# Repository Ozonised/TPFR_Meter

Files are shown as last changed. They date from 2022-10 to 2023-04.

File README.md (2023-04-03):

# TPFR_Meter
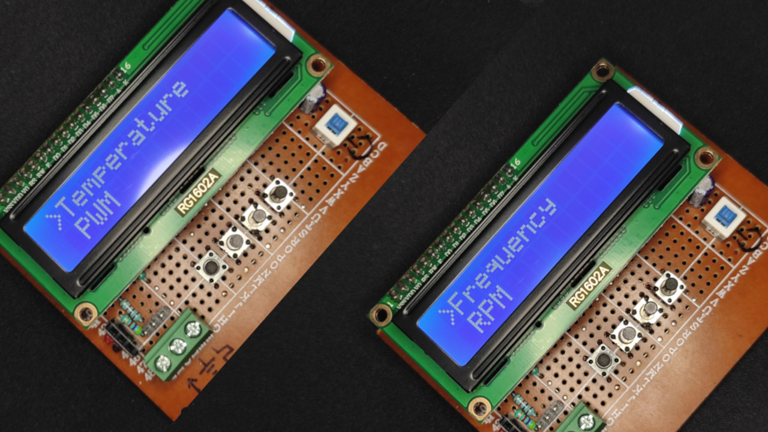
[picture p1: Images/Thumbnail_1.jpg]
TPFR_Meter


This is an ATmega328p based Temperature, PWM generator, Frequency counter and RPM meter. 
# BACK STORY
Often when creating circuits involving MOSFETs or motor drivers, I happen to find a need for a temperature sensor to measure the temperatures of my MOSFETs, a PWM generator to control the speed of motors or to test servos. Not only did have a need for a PWM generator but also a frequency counter when tinkering around with ne555 cicuits based oscillator circuits. Designing separate circuits to fullfill each of my needs would prove to time consuming, expensive and would require additional space to store all the devices. Thus, the idea of creating all purpose meter to measure temperature, generate PWM signals, measure Frequency and RPM struck me which resulted in me creating this multi purpose meter called the TPFR meter. 

# What does TPFR mean?
Well TPFR stands for Temperature(T), PWM(P), Frequency(F) and RPM(R) which is representative of the functionality of this meter.

# FEATURES: 
## 1. TEMPERATURE
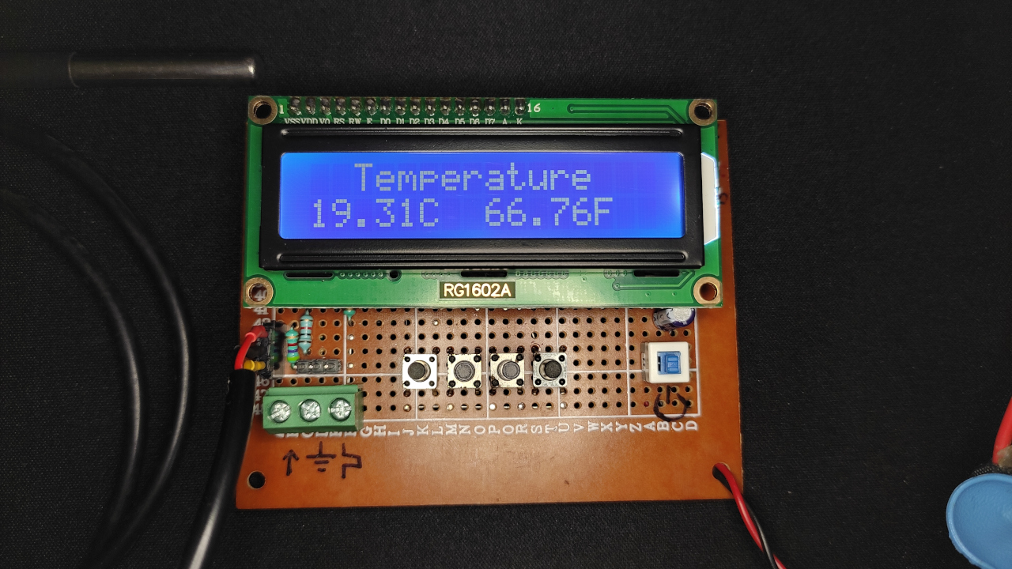
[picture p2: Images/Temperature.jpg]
TEMPERATURE


The temperature measurement is done with the help of a ds18b20 waterproof temperature sensor with a max measurable temperature of 125 degree celsius and a minimum of -55 degree celsius.

## 2. PWM
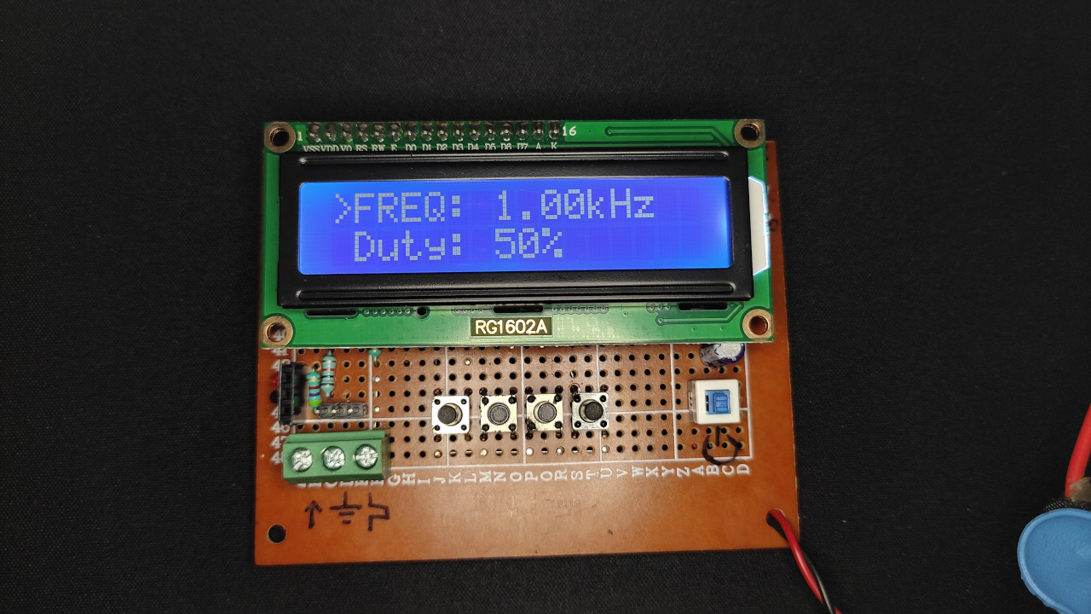
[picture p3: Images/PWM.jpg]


The PWM signals are generated using the timer1 of the 328p with a frequency range of 31Hz - 100KHz and a variable duty cycle from 0 - 100%.
The frequency range is subdivied into 4 ranges:

| Range | Frequency Range |
| :---: | :---: |
| 1 | 31Hz - 1KHz |
| 2 | 1KHz - 10KHz |
| 3 | 10KHz - 40KHz |
| 4 | 40KHz - 100KHz |

## 3. FREQUENCY COUNTER
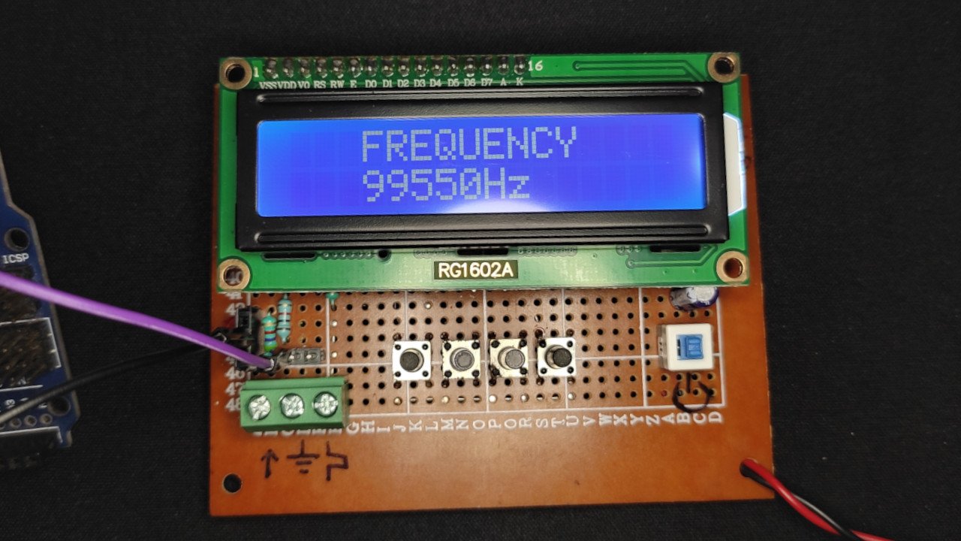
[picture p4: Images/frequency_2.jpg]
FREQUENCY_COUNTER


The frequency counter mode as the name implies measures the frequency of the input signal with an accuracy of 99.8%. The error% is usually around 0.02% - 0.01%. The maximum error% that I recorded was 0.2%. I do not know the maximum measurable frequency since my test setup could only reach a maximum frequency of 100Khz.

## 4. RPM
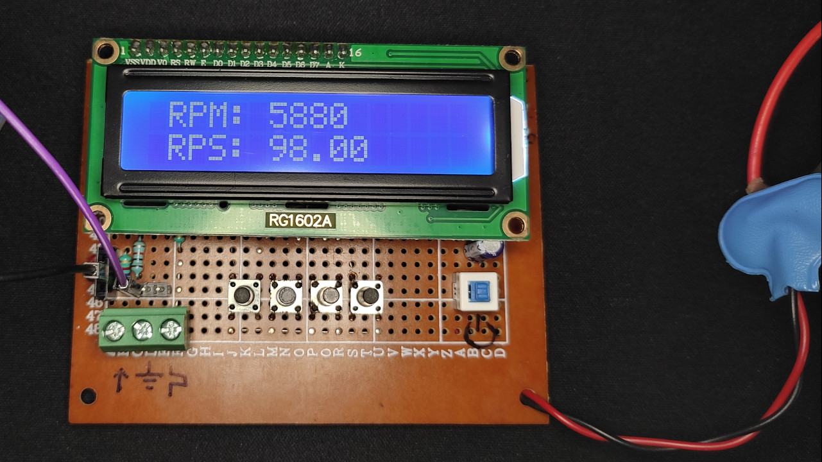
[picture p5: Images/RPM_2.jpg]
RPM


This mode uses the timer1's input capture register to measure the period of the input signal and then computes the revolution per minute(RPM) and the revolution per second(RPS). The maximum measurable RPM is in the vicinity of 100,000 RPM(approx). Unfortunately, I do not have the equipment to measure the actual maximum RPM.

 ### Measuring RPM:
 1. To measure the RPM, an [IR proximity sensor](https://hackster.imgix.net/uploads/attachments/471152/obstacle-avoidance-tracking-infrared-sensor-module_S9CxCA7UqZ.jpg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) is used.
 2. The RPM of the object to measured, a wheel in my case, is covered by a black tape with a white spot on it. The white spot is needed to reflect the IR light which in turn triggers the output of the IR sensor.
 
 ### Note: 
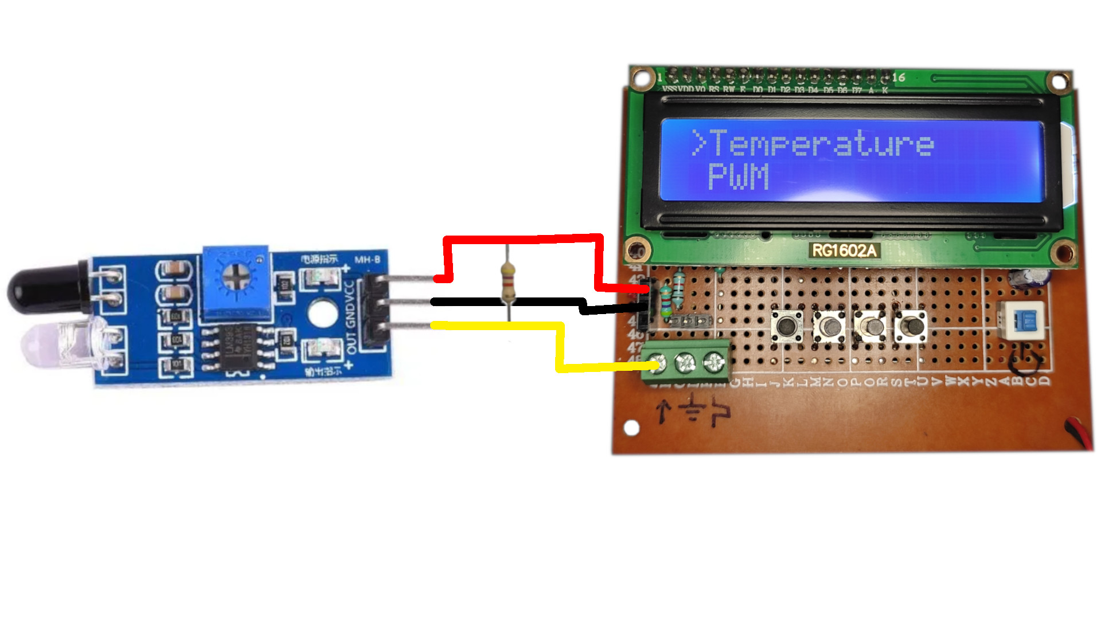
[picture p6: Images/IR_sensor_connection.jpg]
connection of IR sensor
 The output of the IR sensor must be pulled up to VCC using a pull up resistor of 4.7K or so. This is because the IR sensor has an open collector output ,i.e, the output can only be pulled LOW so a pull up resistor is needed to avoid a floating pin. Refer to the connection diagram below: 
 
# ELECTRICAL CHARACTERISTICS:
 | Pin | Voltage |
 | :---: | :---: |
 | Input | 7.5V - 12V |
 | PWM | 5V |
 | Frequency Counter | 5V |
 | dsb18b20 data pin | 5V |

# USER INTERFACE: 
To use the this device, we must be aware of the hardware as well as the software interface and that is what we will be covering in this section starting with the pinout.

## PINOUT:
 Seeing all those switches and connector might seem intimidating at first but don't you worry as that is what I will breaking down in this section.
 
 pinout
 
 Each connector and switch in the picture has been designated with a number to aid with it's identification in the table below:
 
 | Pin No | Function |
 | :----: | :------: |
 | 1 | 5V |
 | 2 | GND |
 | 3 | dsb18b20 data pin |
 | 4 | Frequency counter |
 | 5 | GND |
 | 6 | PWM |
 | 7 | BACK |
 | 8 | UP / Increament |
 | 9 | DOWN / Decreament |
 | 10 | ENTER / SELECT |
 | 11 | Power switch |
 
 ## HOW TO USE:
- Connect a 9v battery and press the power button. 
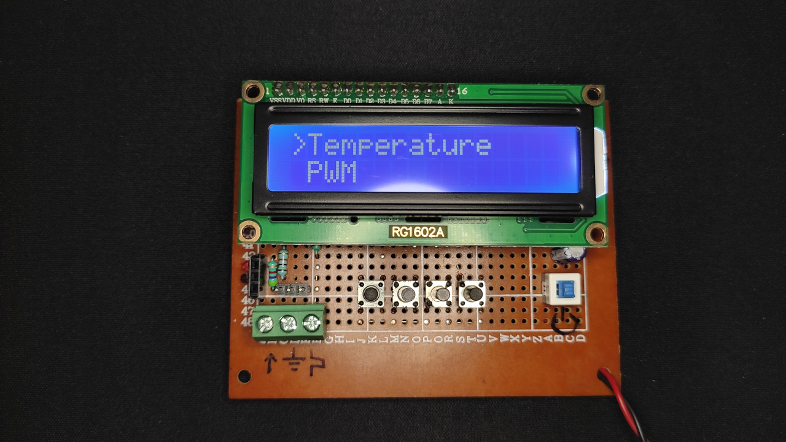
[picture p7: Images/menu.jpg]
menupage
- On startup you will be greated with the homescreen/menupage.  
- The cursor on the right points to the current selected the option. 
- Use the ```UP``` and ```DOWN``` buttons to navigate through the menu.
- Press the ```ENTER``` button to enter the menu or option.
- Press the ```BACK``` button to exit from the current option.

That's the basic on how to use the meter. However taking a look at an example will provide a broader picture.
Let's take the example of the PWM mode:
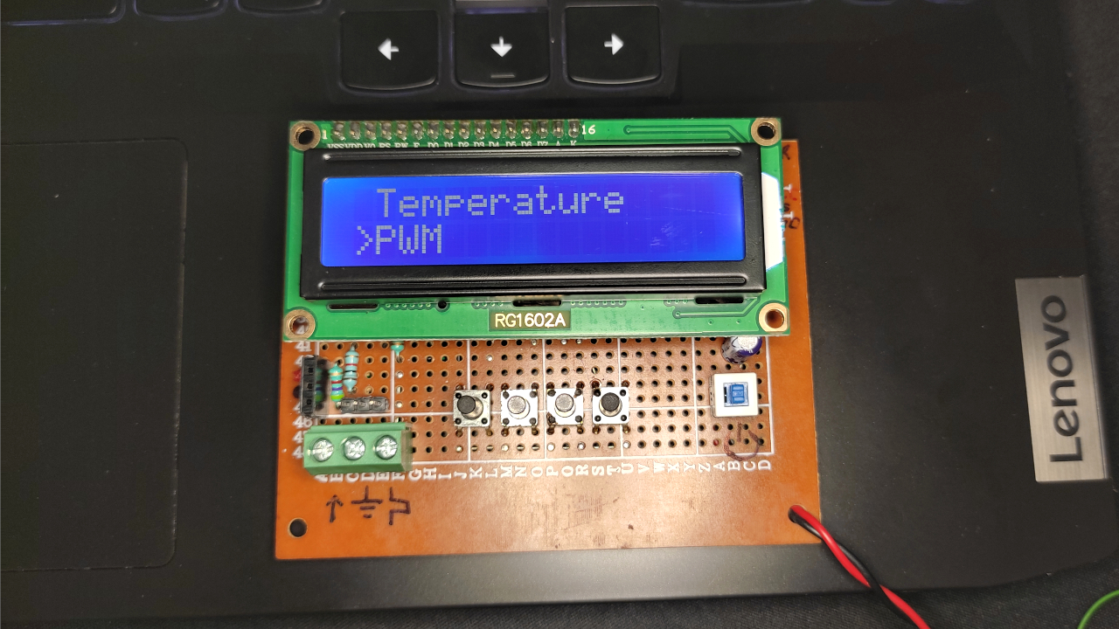
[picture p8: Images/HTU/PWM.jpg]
- Press the ```DOWN``` switch to point the arrow at the ```PWM``` mode. 
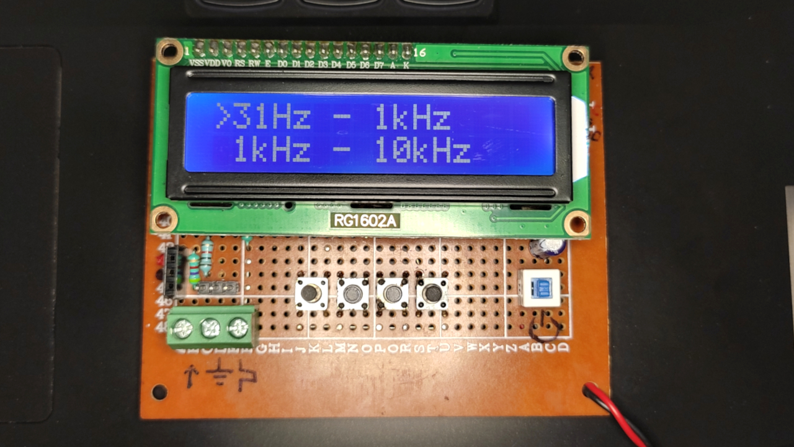
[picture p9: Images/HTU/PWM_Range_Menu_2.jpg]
PWM_Range
- Press ```ENTER``` to enter PWM mode. 
- Now, you will be greeted with the PWM frequency range menu. The PWM frequency range is subdivied into 4 ranges:

   | Range | Frequency Range |
   | :---: | :---: |
   | 1 | 31Hz - 1KHz |
   | 2 | 1KHz - 10KHz |
   | 3 | 10KHz - 40KHz |
   | 4 | 40KHz - 100KHz |
   
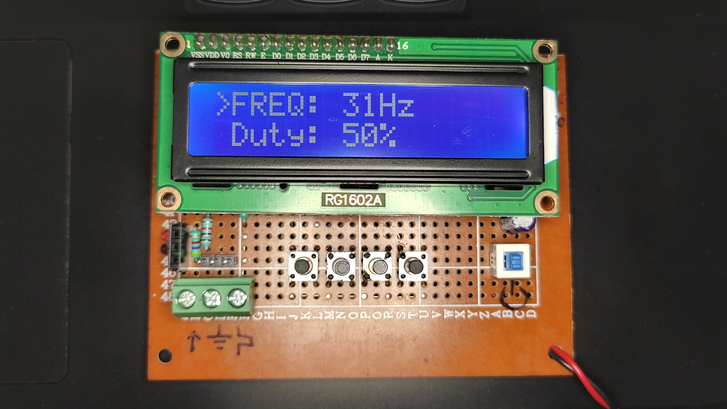
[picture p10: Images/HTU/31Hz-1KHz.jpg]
firstRange
- Let's select the first range(31HZ - 1KHz) by pressing ```ENTER```. 
- Now you will be presented with 2 options and those are frequency(```Freq:```) and  duty cycle (```Duty%:```). By default the frequency is set to the lowest value in the given range(31Hz in this case) while the duty cycle is set to to 50.
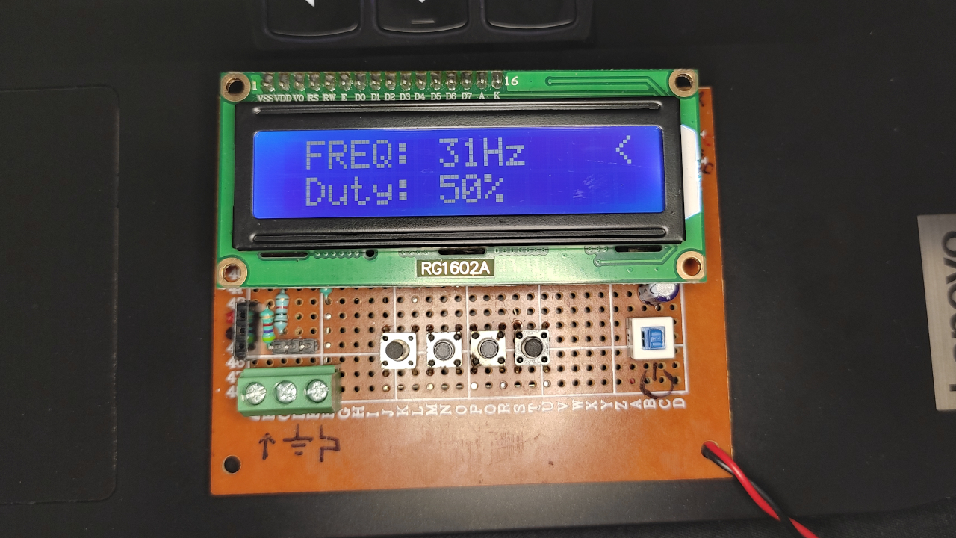
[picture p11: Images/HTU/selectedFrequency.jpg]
freq_edit
- To change the default value, the frequency value in this case, press ```ENTER```. 
- Now the cursor shifts to the right hand side, implying that you are in the value edit mode.
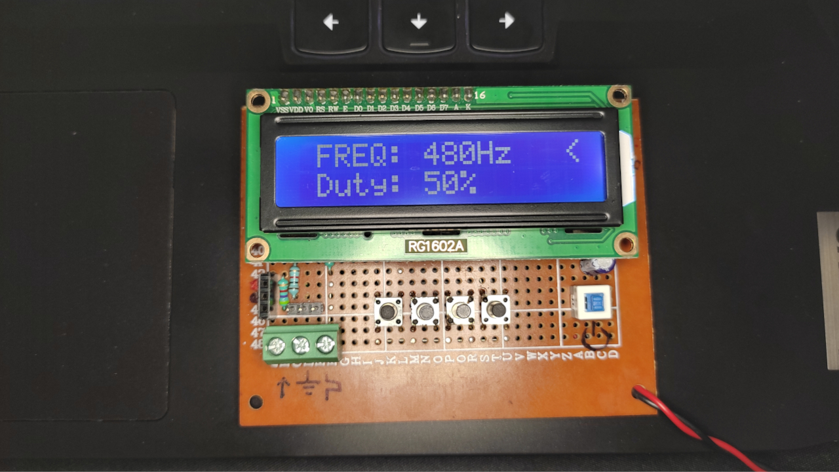
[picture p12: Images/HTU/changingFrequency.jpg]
changingFreq
- Press the ```UP``` or ```DOWN``` button to either increament or decreament the values in single steps or long press the respective button to rapidly increase or decrease the value. 
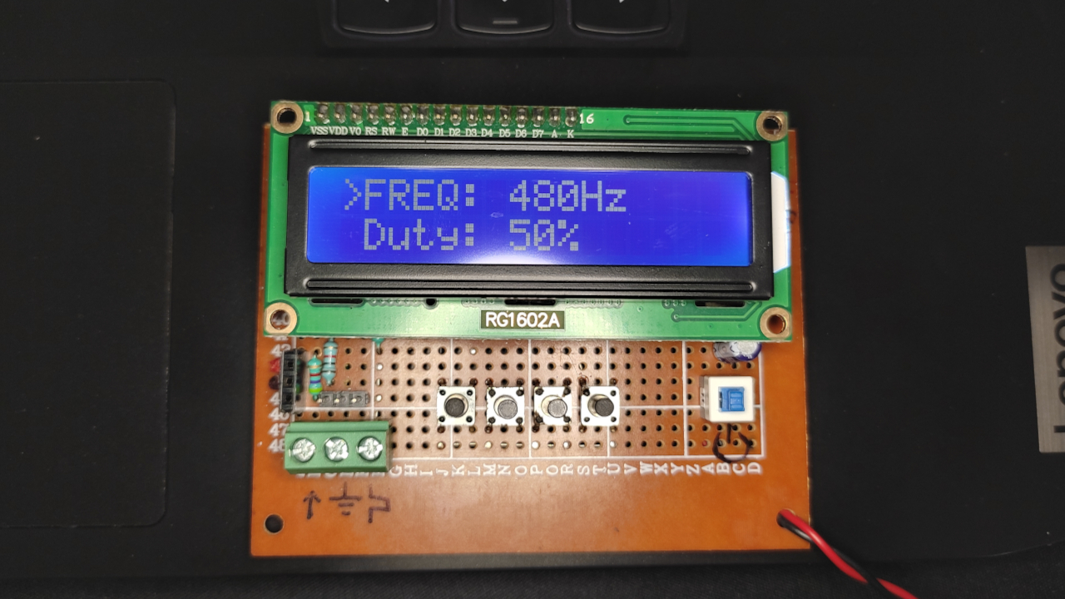
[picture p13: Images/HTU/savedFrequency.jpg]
savingFreq
- Once you have set the desired value, press ```ENTER``` to save it and the cursor moves back to the left hand side. 
- The same steps are applicable for changing the duty cycle value.
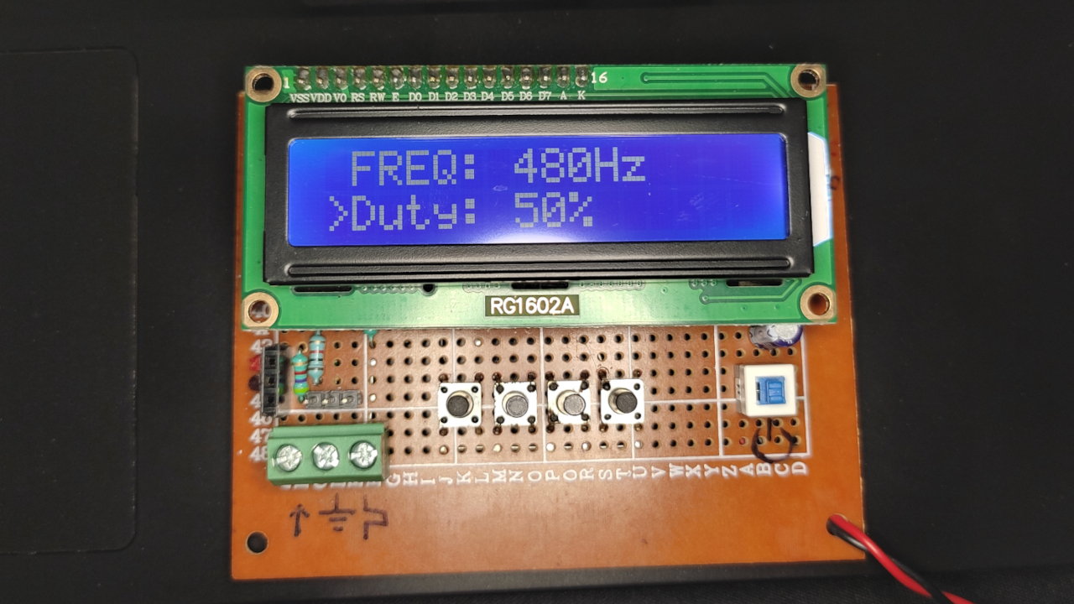
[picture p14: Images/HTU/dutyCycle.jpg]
dutyCycle
- First, press the ```DOWN``` button to select duty cycle. 
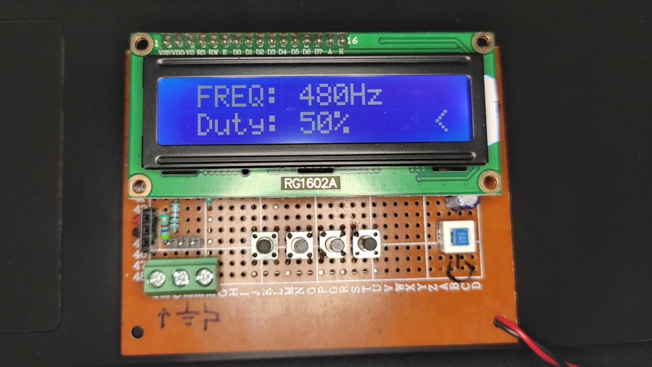
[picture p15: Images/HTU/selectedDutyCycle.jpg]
dutyCycleSelected
- Now press ```ENTER``` to select it and the cursor moves to the right hand side implying you are in the value edit mode. 
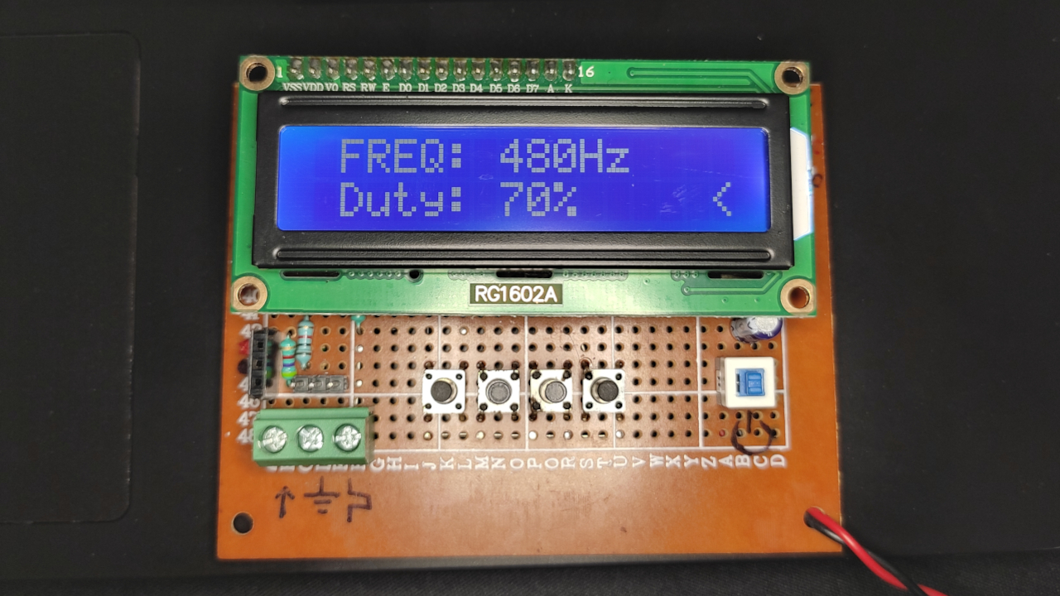
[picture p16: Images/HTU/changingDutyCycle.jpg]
changingDutyCycle
- Now change the value by either pressing the ```UP``` or ```DOWN``` button. The procedure is as the same as the one shown above for frequency. 
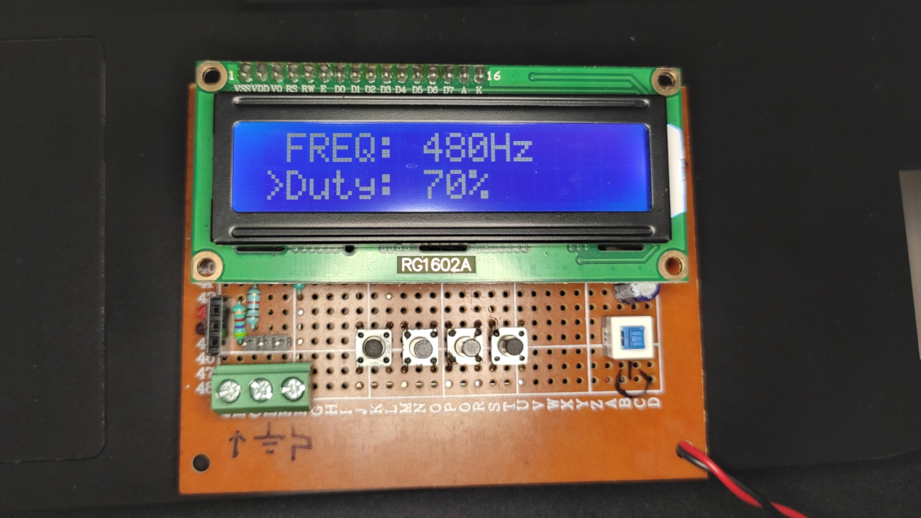
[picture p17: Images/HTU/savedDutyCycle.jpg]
savedDutyCycle
- Press ```ENTER``` to save the value. 
- To exit from the PWM menu, press the ```BACK``` button. PWM_Range
- Press ```BACK``` again to get to the homescreen. PWM

## DONE THIS IS IT! 
This is all you need to know to get started using this meter.

### Note: 
- The frequency and duty cycle change only upon pressing ```ENTER```.
- The frequency increment step is not 1Hz for every range. It changes with the frequency range. The table below shows the shows the frequecny range and it's increament/decreament step value:

| | Frequency Range | Step Value |
| :---: | :---: | :---: |
| 1 | 31Hz - 1KHz | 1Hz |
| 2 | 1KHz - 10KHz | 10Hz |
| 3 | 10KHz - 40KHz | 100Hz |
| 4 | 40KHz - 100KHz | 1000Hz |

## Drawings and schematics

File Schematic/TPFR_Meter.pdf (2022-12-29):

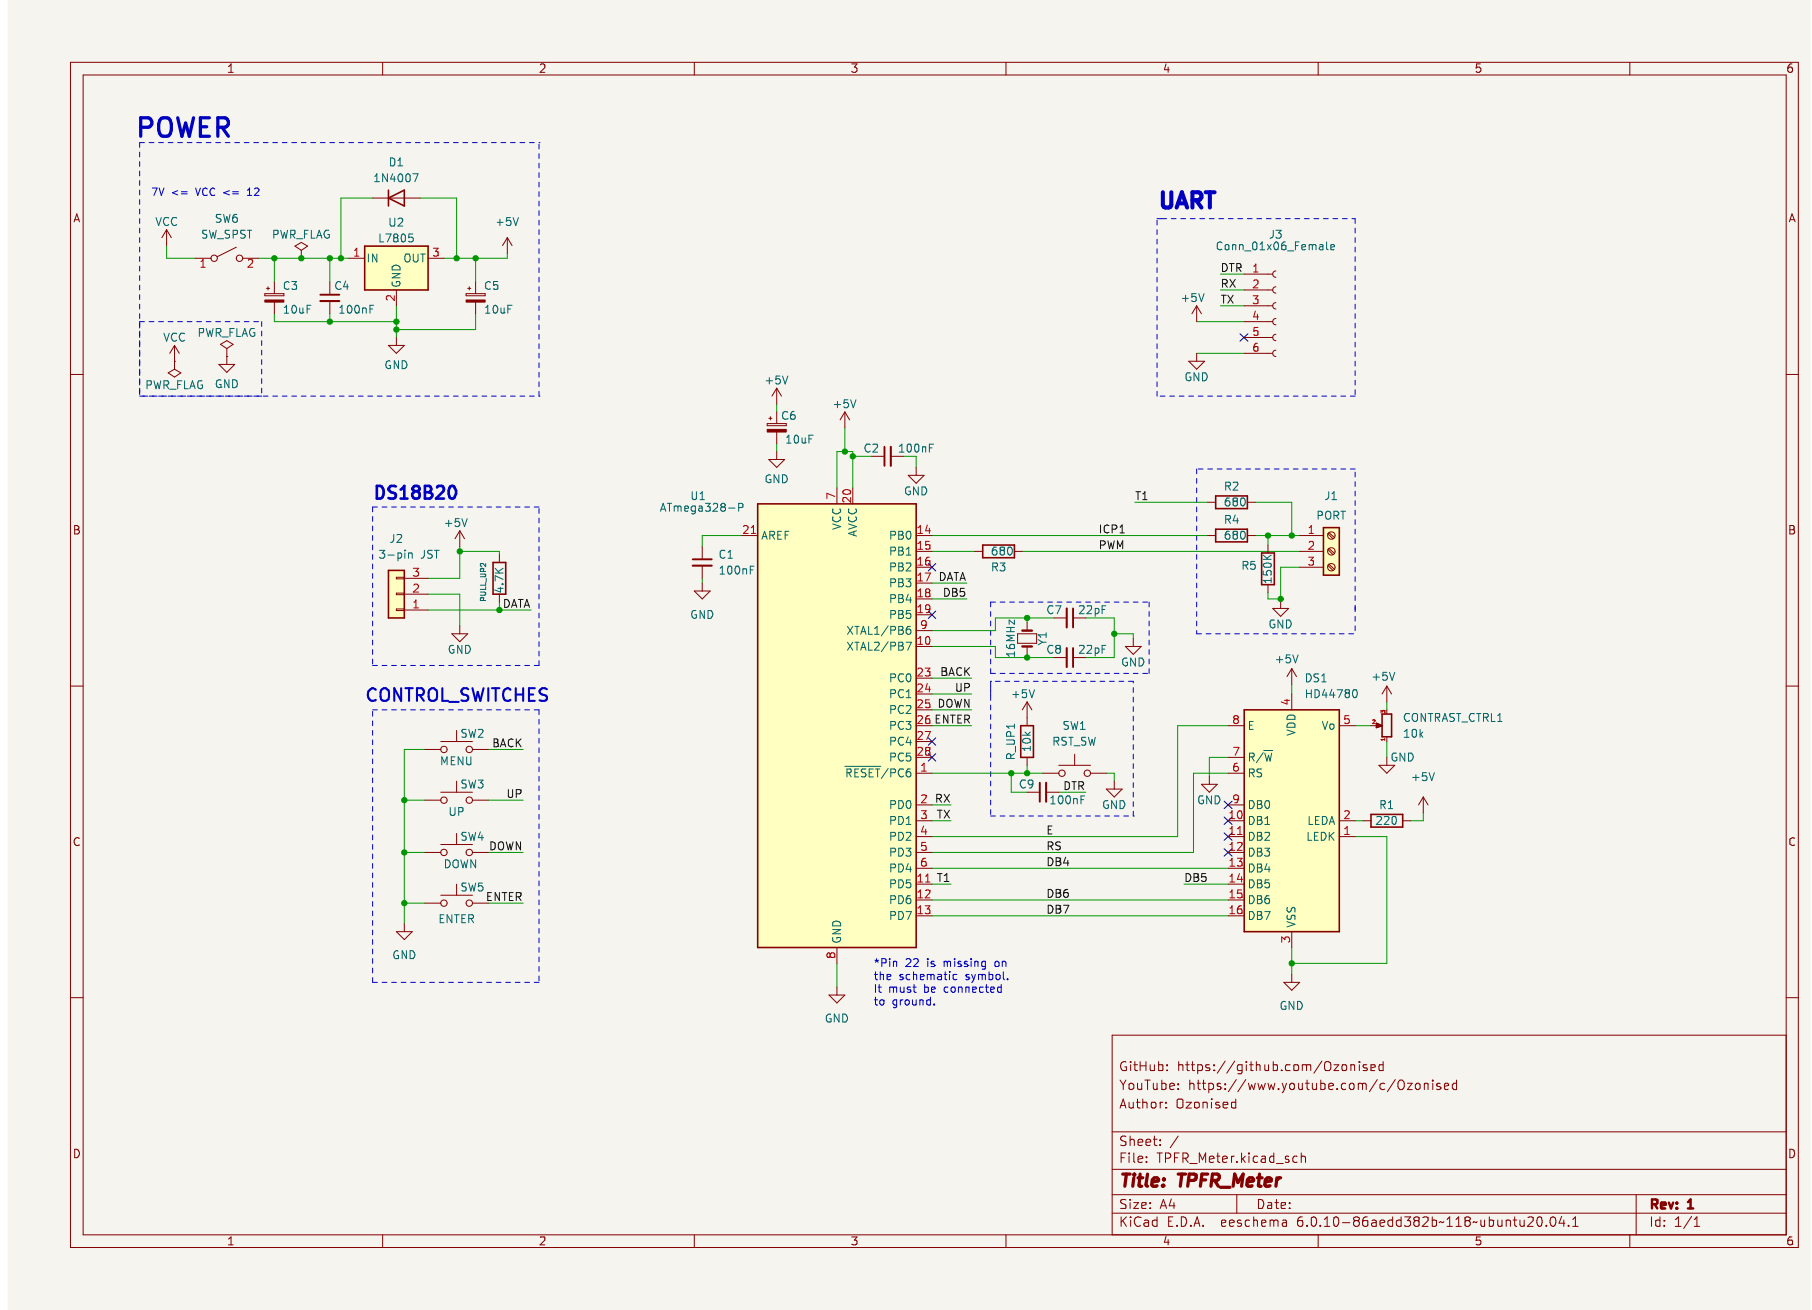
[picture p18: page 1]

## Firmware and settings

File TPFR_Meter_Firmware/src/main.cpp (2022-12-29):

#include <Arduino.h>
#include <LiquidCrystal.h>
#include <avr/pgmspace.h>
#include "switches.h"
#include "modes.h"
#include "home.h"
#include "pwm.h"
#include "temperature.h"
#include "freqCounter.h"
#include "rpm.h"

unsigned long currentMillis;
unsigned long prevSwtReadTime;
const uint8_t SWT_READ_INTERVAL = 15;
uint8_t curntSwtState, prevSwtState;

uint8_t curPos;

const uint8_t E = 2, RS = 3, D4 = 4, D5 = 12, D6 = 6, D7 = 7;
LiquidCrystal lcd(RS, E, D4, D5, D6, D7);

void (*currentMode)(void);

void setup()
{
  // Enabling Pulls ups
  PORTC |= _BV(BACK) | _BV(UP) | _BV(DOWN) | _BV(ENTER);
  lcd.begin(16, 2);
  // Serial.begin(9600);
  updateLCD = 1;
  currentMode = home;
}

void loop()
{
  currentMillis = millis();

  // read the switch state every 15ms
  if ((currentMillis - prevSwtReadTime) >= SWT_READ_INTERVAL)
  {
    curntSwtState = PINC & (_BV(BACK) | _BV(UP) | _BV(DOWN) | _BV(ENTER));

    // checking for long button presses
    // switch states are checked every 15ms
    // a long press has occured if the switch has been pressed for more than 495 ms

    // if the switch is currently pressed and was previously pressed as well and it has not been a long press
    if (curntSwtState == IS_UP && !bitRead(prevSwtState, UP) && !switches.upLongPressed)
    {
      switches.upLongPressed = ++switches.upPressCount >= 33; // ">= 33" because 33 * SWT_READ_INTERVAL = 495ms
    }
    // switch is not pressed
    else if (curntSwtState != IS_UP)
    {
      switches.upPressCount = 0;
      switches.upLongPressed = 0;
    }

    if (curntSwtState == IS_DOWN && !bitRead(prevSwtState, DOWN) && !switches.downLongPressed)
    {
      switches.downLongPressed = ++switches.downPressCount >= 33;
    }
    else if (curntSwtState != IS_DOWN)
    {
      switches.downPressCount = 0;
      switches.downLongPressed = 0;
    }

    prevSwtReadTime = currentMillis;
  }

  // the respective switch is pressed only when it is currently LOW and was previously HIGH
  switches.backPressed = curntSwtState == IS_BACK && bitRead(prevSwtState, BACK);
  switches.upPressed = curntSwtState == IS_UP && bitRead(prevSwtState, UP);
  switches.downPressed = curntSwtState == IS_DOWN && bitRead(prevSwtState, DOWN);
  switches.enterPressed = curntSwtState == IS_ENTER && bitRead(prevSwtState, ENTER);

  if (switches.upPressed || switches.downPressed)
    updateLCD = 1;

  prevSwtState = curntSwtState;

  // decrement curPos only when it's greater than zero
  curPos -= switches.upPressed && curPos;
  // increment curPos only when it's less than 3
  curPos += switches.downPressed && curPos < 3;

  currentMode();
}

// void printMenu(PGM_P const *str)
// {
//   lcd.clear();
//   switch (curPos)
//   {
//   case 0:
//   case 1:
//     strcpy_P(lcdStr, (PGM_P)pgm_read_word(&str[0]));
//     lcd.print(lcdStr);
//     strcpy_P(lcdStr, (PGM_P)pgm_read_word(&str[1]));
//     lcd.setCursor(0, 1);
//     lcd.print(lcdStr);
//     lcd.setCursor(0, curPos);
//     lcd.print('>');
//     break;

//   case 2:
//   case 3:
//     strcpy_P(lcdStr, (PGM_P)pgm_read_word(&str[2]));
//     lcd.print(lcdStr);
//     strcpy_P(lcdStr, (PGM_P)pgm_read_word(&str[3]));
//     lcd.setCursor(0, 1);
//     lcd.print(lcdStr);
//     lcd.setCursor(0, curPos % 2);
//     lcd.print('>');
//     break;

//   default:
//     break;
//   }
// }

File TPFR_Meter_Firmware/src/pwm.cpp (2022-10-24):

#include "pwm.h"

int32_t cpuClkOffset = 0;

static uint8_t current_PWM_Range;
static uint16_t increment_step;
static uint32_t currentMinFreq;
static uint32_t current_PWM_Freq;
static uint32_t currentMaxFreq;
static uint32_t PWM_Duty_Cycle;
static uint32_t prevIncrementTime;

PWM_Freq_Range const pwmFreq[4] PROGMEM = {
    {31, 1000, 1},
    {1000, 10000, 10},
    {10000, 40000, 100},
    {40000, 100000, 1000}};

static const char PWM_R0[] PROGMEM = " 31Hz - 1kHz";
static const char PWM_R1[] PROGMEM = " 1kHz - 10kHz";
static const char PWM_R2[] PROGMEM = " 10kHz - 40kHz";
static const char PWM_R3[] PROGMEM = " 40kHz - 100kHz";

PGM_P const pwmRangeMenu[] PROGMEM = {PWM_R0, PWM_R1, PWM_R2, PWM_R3};

void pwm();
static void set_PWM_Freq(uint32_t freq, uint32_t dutyCycle, uint8_t range);
static void set_PWM_DutyCycle(uint32_t dutyCycle);

void set_PWM_Freq(uint32_t freq, uint32_t dutyCycle, uint8_t range)
{
    uint16_t temp_ICR1 = 0;
    uint8_t prescaler;

    // Fast non-inverted PMW with ICR1 as top
    TCCR1A = _BV(COM1A1) | _BV(WGM11);
    TCCR1B = _BV(WGM13) | _BV(WGM12);

    if (range)
    {
        // prescaler = 1 for frequency range 1kHz - 100kHz
        TCCR1B &= ~_BV(CS11);
        TCCR1B |= _BV(CS10);
        prescaler = 1;
    }
    else
    {
        // prescaler = 8 for frequency range 31Hz - 1kHz
        TCCR1B &= ~_BV(CS10);
        TCCR1B |= _BV(CS11);
        prescaler = 8;
    }

    temp_ICR1 = ((F_CPU / prescaler) / freq) - 1;

    // update the frequency only if ICR1 has changed
    // temp_ICR1 will not be equal to ICR1 if the frequency has changed
    if (temp_ICR1 != ICR1)
    {
        TCNT1 = 1;
        ICR1 = temp_ICR1;
    }
    OCR1A = (temp_ICR1 * dutyCycle) / 100;

    // PWM pin as output
    bitSet(DDRB, PWM_PIN);
}

void set_PWM_DutyCycle(uint32_t dutyCycle)
{
    OCR1A = (ICR1 * dutyCycle) / 100;
}

void PWM_Range_Select()
{
    if (updateLCD)
    {
        lcd.clear();
        switch (curPos)
        {
        case 0:
        case 1:
            strcpy_P(lcdStr, (PGM_P)pgm_read_word(&pwmRangeMenu[0]));
            lcd.print(lcdStr);
            strcpy_P(lcdStr, (PGM_P)pgm_read_word(&pwmRangeMenu[1]));
            lcd.setCursor(0, 1);
            lcd.print(lcdStr);
            lcd.setCursor(0, curPos);
            lcd.print('>');
            break;

        case 2:
        case 3:
            strcpy_P(lcdStr, (PGM_P)pgm_read_word(&pwmRangeMenu[2]));
            lcd.print(lcdStr);
            strcpy_P(lcdStr, (PGM_P)pgm_read_word(&pwmRangeMenu[3]));
            lcd.setCursor(0, 1);
            lcd.print(lcdStr);
            lcd.setCursor(0, curPos % 2);
            lcd.print('>');
            break;

        default:
            break;
        }
        updateLCD = 0;
    }

    if (switches.enterPressed)
    {
        currentMode = pwm;
        current_PWM_Range = curPos;
        curPos = 0;

        currentMinFreq = pgm_read_dword(&pwmFreq[current_PWM_Range].MIN_FREQ); // minimum frequency for the selected range
        currentMaxFreq = pgm_read_dword(&pwmFreq[current_PWM_Range].MAX_FREQ); // maximum frequency for the selected range
        increment_step = pgm_read_word(&pwmFreq[current_PWM_Range].STEP);      // increment or decrement step size for the selected range
        current_PWM_Freq = currentMinFreq;                                     // default frequency
        PWM_Duty_Cycle = 50;                                                   // default duty cycle

        set_PWM_Freq(current_PWM_Freq, PWM_Duty_Cycle, current_PWM_Range);

        updateLCD = 1;
    }

    if (switches.backPressed)
    {
        currentMode = home;
        curPos = PWM_RANGE - 1; // cursor at row one
        updateLCD = 1;
    }
}

void pwm()
{
    static bool setFreq = 0;
    static bool setDuty = 0;
    static uint8_t pwmCur = 0;

    // increment or decrement pwmCur only when we are not in setFreq or setDuty mode
    if (!setFreq && !setDuty)
    {
        // decrement pwmCur only when it's greater than zero
        pwmCur -= switches.upPressed && pwmCur;
        // increment pwmCur only when it's less than 1
        pwmCur += switches.downPressed && pwmCur < 1;
    }

    if (switches.enterPressed)
    {
        switch (pwmCur)
        {
        case 0:
            // set frequency mode
            setDuty = 0;
            setFreq = !setFreq;
            break;

        case 1:
            // set duty cycle mode
            setFreq = 0;
            setDuty = !setDuty;
            break;

        default:
            break;
        }

        updateLCD = 1;
    }

    if (setFreq)
    {
        if (current_PWM_Freq < currentMaxFreq)
        {
            if (switches.upPressed)
                current_PWM_Freq += increment_step;

            // for long button press increment the current_PWM_Freq every 50ms
            if (switches.upLongPressed && (currentMillis - prevIncrementTime) >= 50)
            {
                current_PWM_Freq += increment_step;
                prevIncrementTime = currentMillis;
                updateLCD = 1;
            }
        }

        if (current_PWM_Freq > currentMinFreq)
        {
            if (switches.downPressed)
                current_PWM_Freq -= increment_step;

            // for long button press decrement the current_PWM_Freq every 50ms
            if (switches.downLongPressed && (currentMillis - prevIncrementTime) >= 50)
            {
                current_PWM_Freq -= increment_step;
                prevIncrementTime = currentMillis;
                updateLCD = 1;
            }
        }

        set_PWM_Freq(current_PWM_Freq, PWM_Duty_Cycle, current_PWM_Range);
    }

    if (setDuty)
    {
        PWM_Duty_Cycle += switches.upPressed && PWM_Duty_Cycle < 100;
        PWM_Duty_Cycle -= switches.downPressed && PWM_Duty_Cycle;

        if (switches.upLongPressed && (currentMillis - prevIncrementTime) >= 50)
        {
            PWM_Duty_Cycle += PWM_Duty_Cycle < 100;
            prevIncrementTime = currentMillis;
            updateLCD = 1;
        }

        if (switches.downLongPressed && (currentMillis - prevIncrementTime) >= 50)
        {
            PWM_Duty_Cycle -= PWM_Duty_Cycle > 0;
            prevIncrementTime = currentMillis;
            updateLCD = 1;
        }

        set_PWM_DutyCycle(PWM_Duty_Cycle);
    }

    if (updateLCD)
    {
        lcd.clear();
        lcd.print(F(" FREQ: "));

        // set the display resolution depending on the PWM range
        switch (current_PWM_Range)
        {
        case 0:
            lcd.print(current_PWM_Freq);
            lcd.print("Hz");
            break;

        case 1:
            lcd.print(current_PWM_Freq / 1000.0);
            lcd.print(F("kHz"));
            break;

        case 2:
            lcd.print(current_PWM_Freq / 1000.0, 1);
            lcd.print(F("kHz"));
            break;

        case 3:
            lcd.print(current_PWM_Freq / 1000);
            lcd.print(F("kHz"));
            break;
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

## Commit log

2022-10-05 modified pwm mode
    added feature to reset timer1's registers on exiting PWM mode
    [main.cpp, pwm.cpp]
2022-10-06 added long button press detection
    UP and DOWN button long presses can now be detected
2022-10-06 modified pwm()
    frequency and duty cycle value can now be altered at a faster pace through long button presses
2022-10-24 commit from linux
    [TPFR_Meter.kicad_sch]
2022-10-30 updated schematic
    [TPFR_Meter.kicad_sch]
2022-12-29 frequency counter
    added frequency counting feature, updated schematic and organised all the common includes and variables into common.h
2023-01-01 updated freqCounter.cpp
    added timer1 overflow count in ICR measurement method
2023-05-14 updated schematic & footprint
    added a barrel jack for power input, updated footprints of the symbol and changed the input switch
    [TPFR_Meter.kicad_sch]
2023-05-14 symbols & footprint
    updated LCD symbol and footprint, changed UART & dsb18b20 connectors to female sockets
    [TPFR_Meter.kicad_sch]
